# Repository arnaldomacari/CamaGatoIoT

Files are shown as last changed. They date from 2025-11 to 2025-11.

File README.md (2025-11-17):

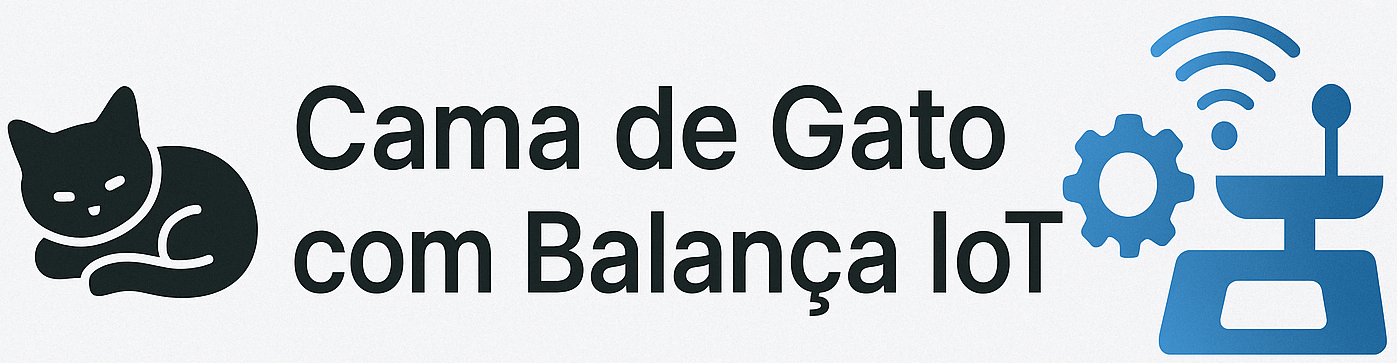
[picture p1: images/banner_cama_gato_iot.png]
Banner do Projeto


<p align="center">
  <span style="font-size:18px; color:blue; font-style:italic;">
    <b>Monitoramento automático de peso e comportamento de felinos com ESP32-C3 Super Mini, HX711 e integração com Google Sheets e Blynk.</b>
  </span>
</p>

---

<p align="center">
  
  
  
  
  
  
</p>

---

## 📘 Resumo

O projeto **Cama de Gato com Balança IoT** propõe o monitoramento automatizado do peso de felinos domésticos, permitindo detectar variações corporais associadas a condições fisiológicas ou patológicas. O sistema usa uma base com **células de carga e módulo HX711**, controlados por um **ESP32-C3** que opera em deep sleep para economizar energia e desperta periodicamente para coletar e enviar dados.

As medições são transmitidas automaticamente para:
- uma **planilha no Google Sheets**, que mantém o histórico e facilita análises;
- o **aplicativo Blynk**, onde o tutor acompanha leituras em tempo real e dispara medições manuais.

---

## 🧠 Objetivos

- Detectar variações sutis de peso corporal em gatos, indicando possíveis doenças metabólicas ou alterações alimentares.
- Desenvolver um sistema de monitoramento contínuo, não invasivo, de baixo custo e com conectividade em nuvem.
- Contribuir para estudos e práticas de bem-estar animal e telemetria veterinária.

---

## 📝 Justificativa

De acordo com dados do Instituto Pet Brasil apresentados por LUCCA (2025) no Correio Braziliense, estima-se que os lares brasileiros já abrigam mais de 30 milhões de gatos. A ABINPET (2025) projeta crescimento de 3,5% para o setor pet no mesmo ano, com faturamento que pode chegar a R$ 78 bilhões. Apesar desse cenário favorável, um estudo com 19 milhões de gatos nos Estados Unidos mostrou que 52% deles tiveram a saúde acompanhada apenas uma vez durante toda a vida, sendo o peso corporal um dos indicadores mais simples e relevantes (CAMPIGOTTO et al., 2019). O trabalho também elaborou uma curva de peso em função da idade, útil como referência em consultas veterinárias. O controle do peso corporal tem relação direta com a longevidade: segundo Pennell et al. (2019), em labradores com mais de dez anos, um desvio de apenas 1 kg aumentou em 19% a probabilidade de morte. Por fim, matéria da University of Guelph (2019) destaca que pequenas variações de peso podem indicar problemas de saúde subjacentes, reforçando a recomendação pelo uso contínuo de balanças. 

Alterações discretas no peso corporal são, muitas vezes, os primeiros sinais de enfermidades em felinos e tendem a passar despercebidas em rotinas domésticas convencionais. Ao unir sensores de baixo custo, computação embarcada eficiente e integração com plataformas de visualização de dados, o projeto possibilita acompanhamento longitudinal, embasando decisões veterinárias mais rápidas e assertivas. A solução também serve como prova de conceito para orientar práticas de bem-estar animal apoiadas por IoT, incentivando a comunidade a adaptar e expandir o sistema conforme necessidades específicas.

---

## ⚙️ Arquitetura do Sistema

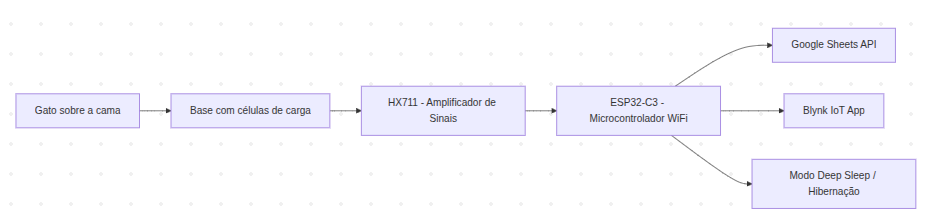
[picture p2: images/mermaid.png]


---

## 🧰 Escolha de Materiais
As células de carga, que transformam o peso do gato em sinal elétrico, precisam ser posicionadas corretamente para que o peso gere uma força de cisalhamento adequada. Para isso, foi desenhado no Onshape um pé e um suporte, mostrados abaixo, que depois foram impressos em 3D usando PLA. O pé e o suporte, junto com a própria célula, também têm a função de elevar a base de MDF onde tudo está fixado, criando um espaço por baixo para a passagem da fiação e para acomodar o circuito eletrônico sem que ambos encostem no chão.
Nos diagramas de Ashby, o MDF aparece na região das madeiras, tem densidade intermediária (600–800 kg/m³) e módulo entre 2–4 GPa. Essa posição o caracteriza como um material rígido, relativamente leve e adequado para estruturas que exigem estabilidade dimensional e baixo custo. No projeto, foi utilizada uma base circular de MDF com raio de 50 cm, espessura de 15 mm e pintada com camadas generosas de tinta epóxi. Essa pintura garante fácil assepsia e alta durabilidade, como mostrado na foto da página anterior.
A caixa do circuito e o porta-fio central também foram impressos em 3D. A manufatura aditiva foi escolhida para o protótipo pela agilidade de produção, considerando a definição da função mecânica da estrutura (rigidez + estabilidade + baixo peso). Na análise de restrições (tamanho, peso do gato e deformação mínima da base), a seleção do polímero PLA levou em conta a facilidade de impressão, baixa deformação, custo, estética e, para garantir maior rigidez, foi utilizado 60% de preenchimento. Inicialmente, usando um paquímetro, foram desenhados no Onshape, com precisão, a célula de carga, a placa do circuito eletrônico (já previamente construída) e a bateria. Com esses elementos modelados, foi possível construir ao redor deles o pé, o suporte, a base do circuito e a caixa.

## 🧩 Componentes Utilizados

| Componente | Função | Observações |
| --- | --- | --- |
| **ESP32-C3** | Microcontrolador principal | Comunicação Wi-Fi e deep sleep |
| **HX711** | Conversor ADC 24 bits | Leitura das células de carga |
| **Células de carga** | Sensor de peso | Montadas em ponte de Wheatstone |
| **Sensor capacitivo** | Interação do usuário | Acorda o sistema do modo de hibernação |
| **Divisor resistivo (R1=R2)**| Monitoramento da bateria | Lido pelo ADC do ESP32-C3 |
| **Fonte/Bateria 5V ou LiPo** | Alimentação | Requer estabilidade para leituras precisas |
| **Google Apps Script** | Integração com planilha | Recebe POST JSON do ESP32-C3 |
| **Blynk App (Free Tier)** | Interface do usuário | Widgets V0, V1, V4, V8 e V9 configurados |
| **Placa perfurada 7cm x 3cm**| Alternativa a placa CI | Suporte aos módulos no 1° teste |

---

## ⚡ Circuitos
### Visão geral da conexão entre ESP32-C3, HX711, células de carga e alimentação.

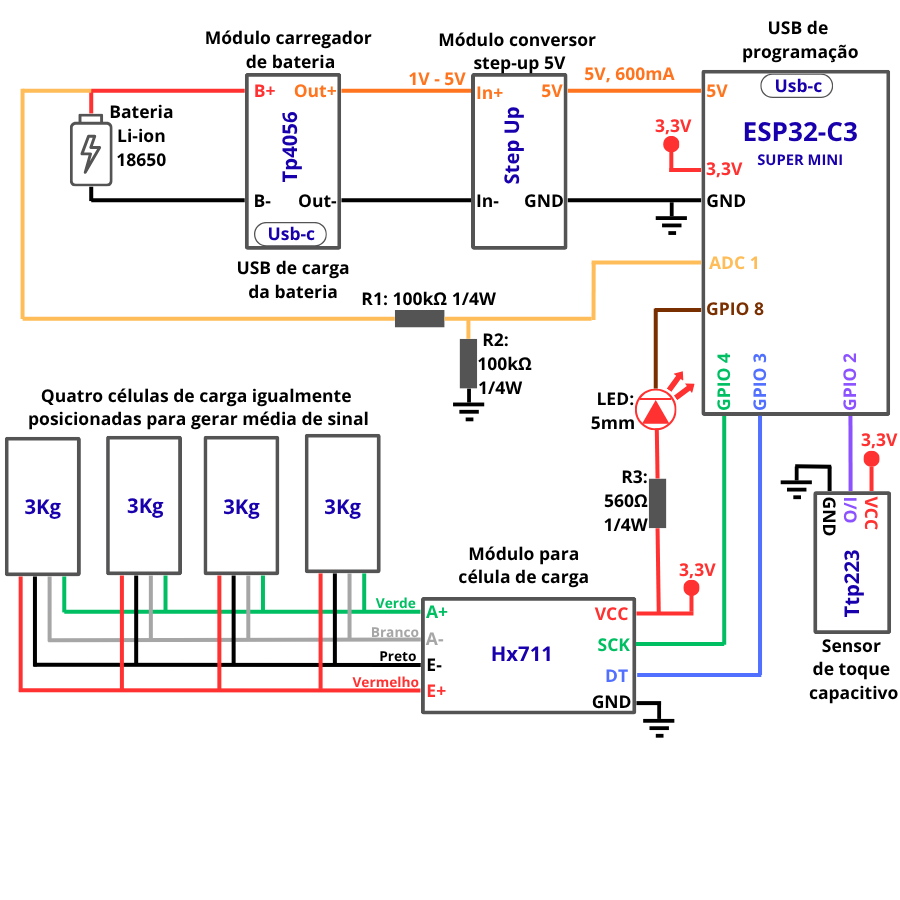
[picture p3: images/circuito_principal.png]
Circuito_principal


---

## 🖼️ Imagens do Protótipo
### Partes mecânicas
#### Pés e bases para células de carga
Usados para posicionar corretamente as células de carga, garantindo que o peso do gato provoque a deformação adequada.

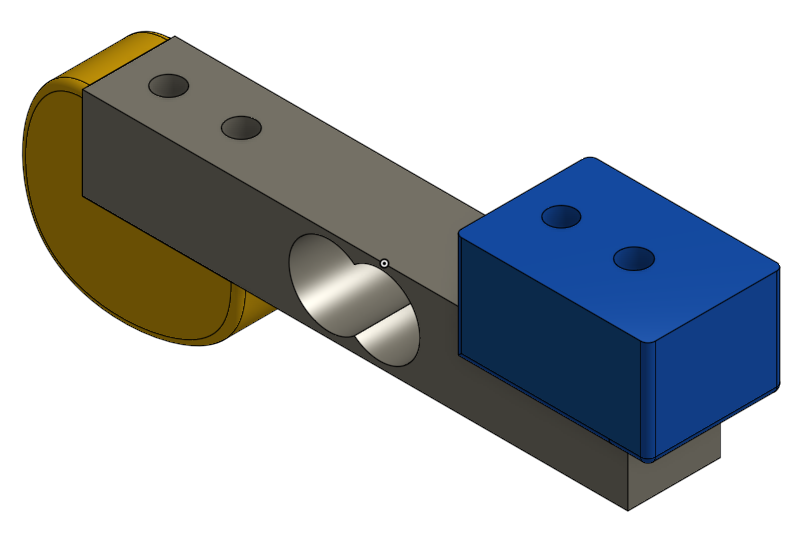
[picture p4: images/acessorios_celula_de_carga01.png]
Acessorios_Celula_de_Carga

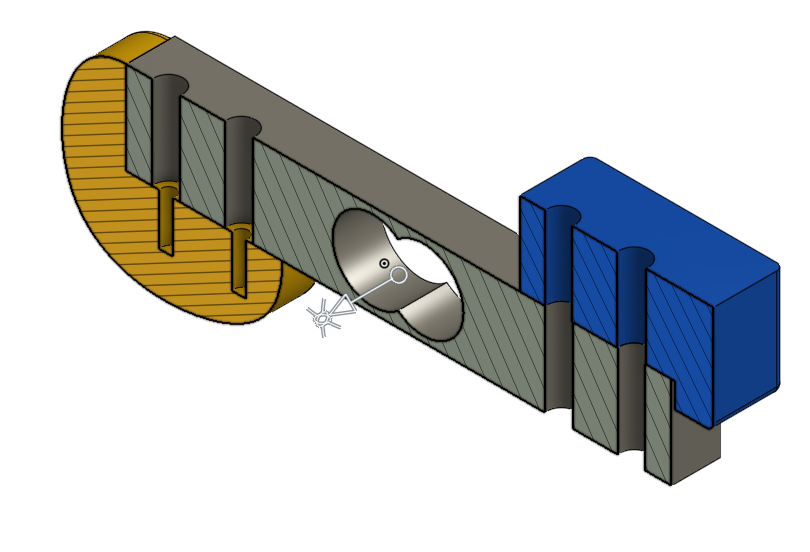
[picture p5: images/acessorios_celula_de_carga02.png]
Acessorios_Celula_de_Carga


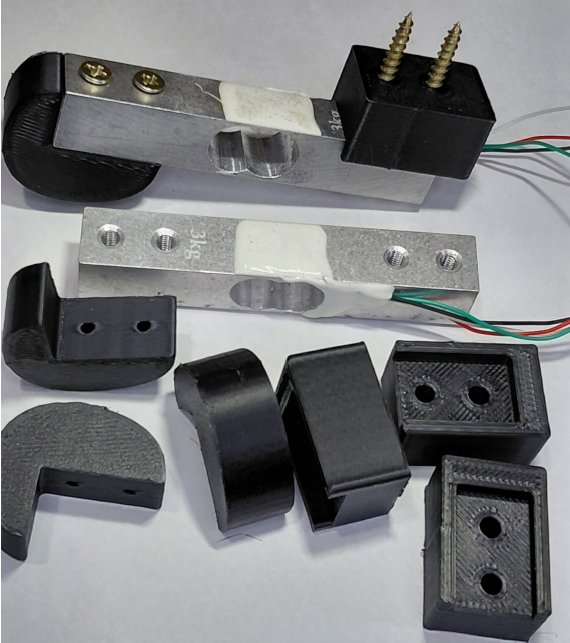
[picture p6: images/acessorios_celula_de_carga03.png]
Acessorios_Celula_de_Carga

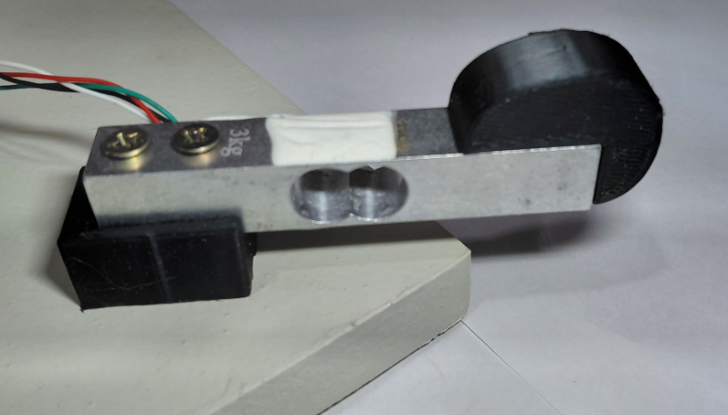
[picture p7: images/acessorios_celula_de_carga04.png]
Acessorios_Celula_de_Carga

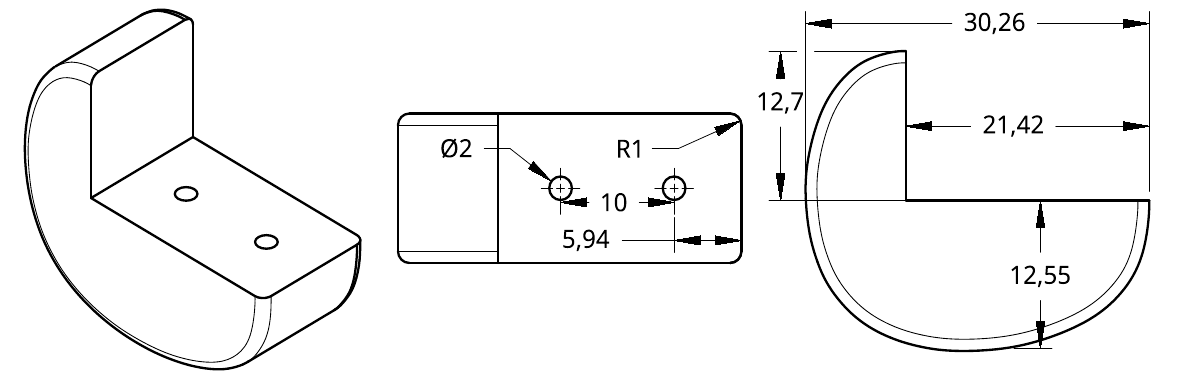
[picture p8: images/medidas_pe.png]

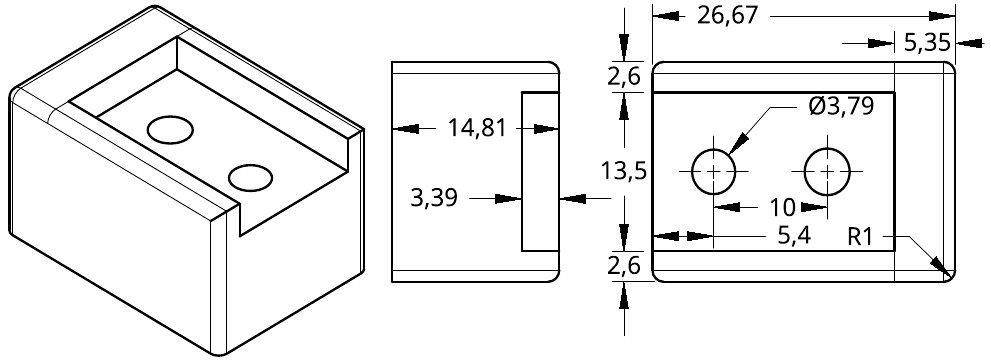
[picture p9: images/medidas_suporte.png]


#### Organizador de fios 
Usado para esticar e esconder as emendas de fios das células de carga com o cabo que segue para a caixa de circuitos.

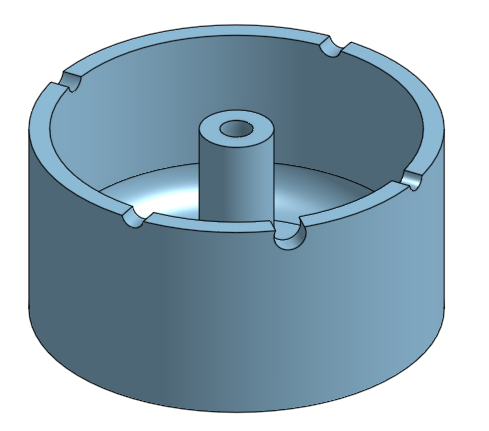
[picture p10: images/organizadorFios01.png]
Organizador1

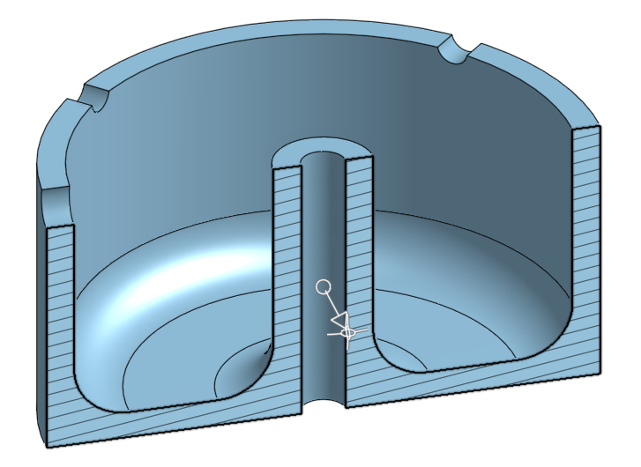
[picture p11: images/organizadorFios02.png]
Organizador2

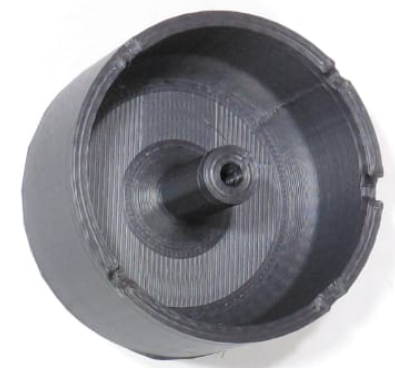
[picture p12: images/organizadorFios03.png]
Organizador3

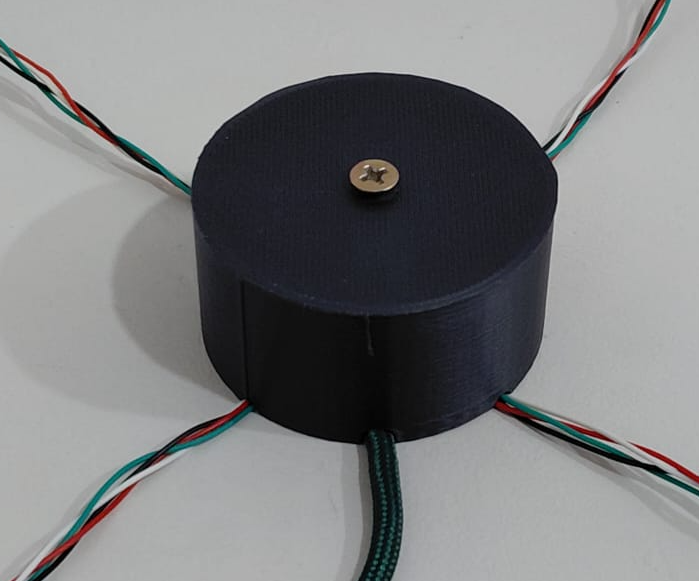
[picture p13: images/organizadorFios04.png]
Organizador4

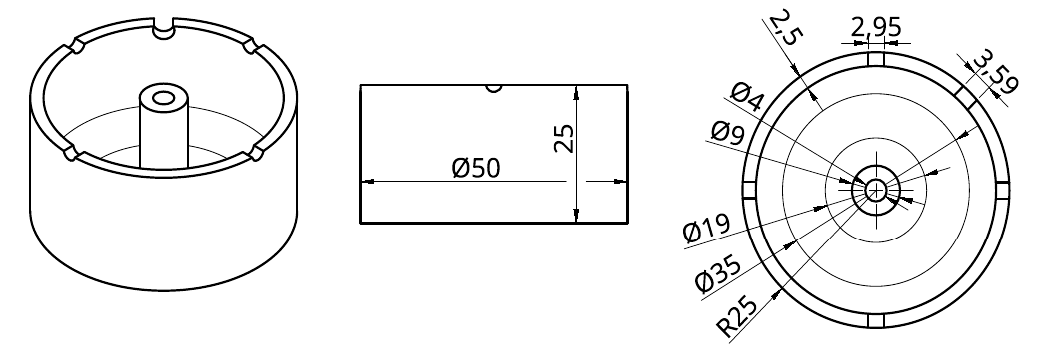
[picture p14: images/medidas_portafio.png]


#### Caixa de circuitos
Caixa que abriga os circuitos, posicionando adequadamente a placa, a bateria, o LED e o botão.
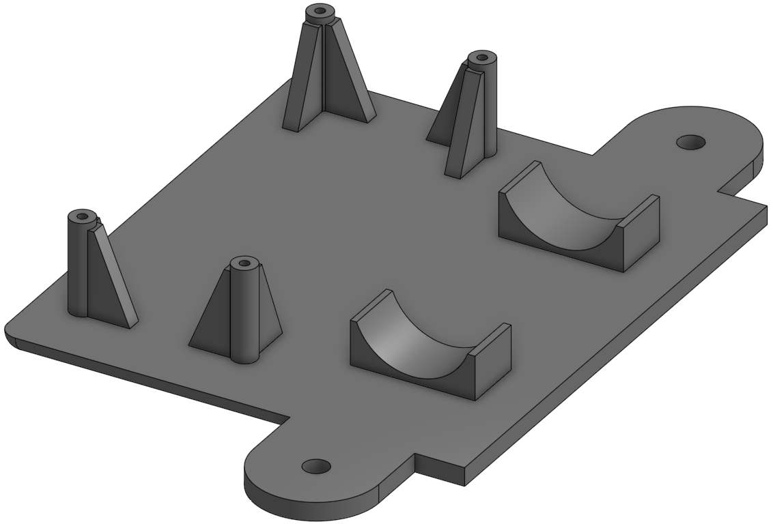
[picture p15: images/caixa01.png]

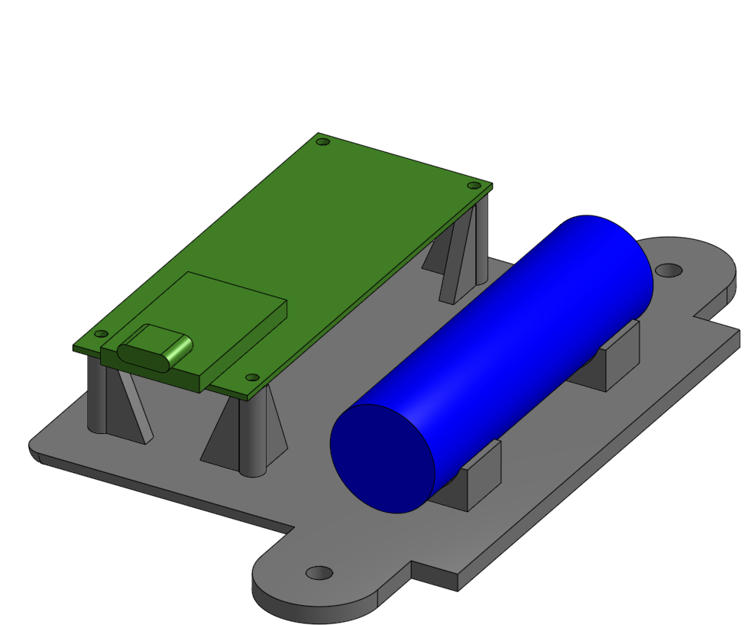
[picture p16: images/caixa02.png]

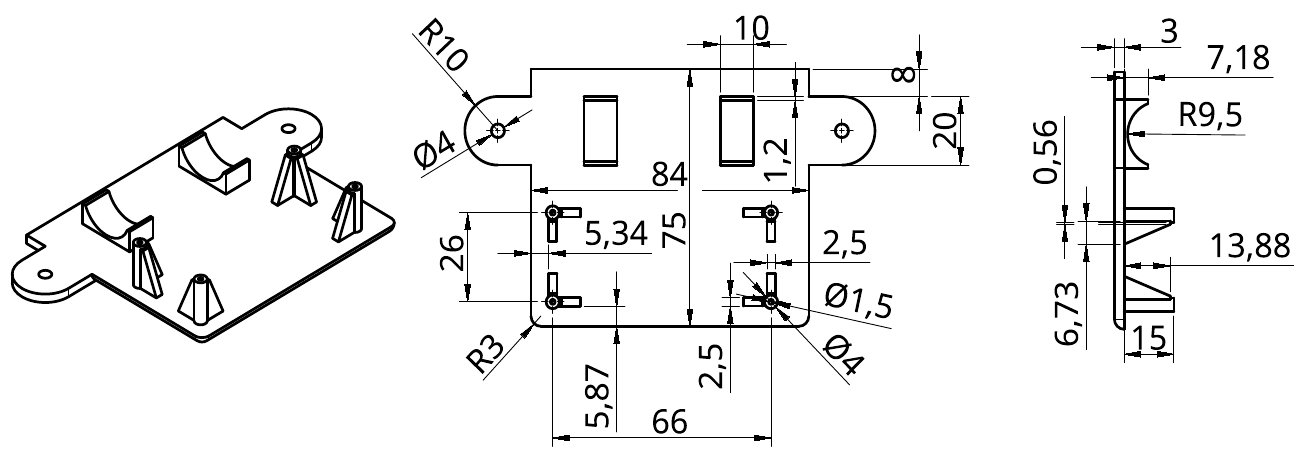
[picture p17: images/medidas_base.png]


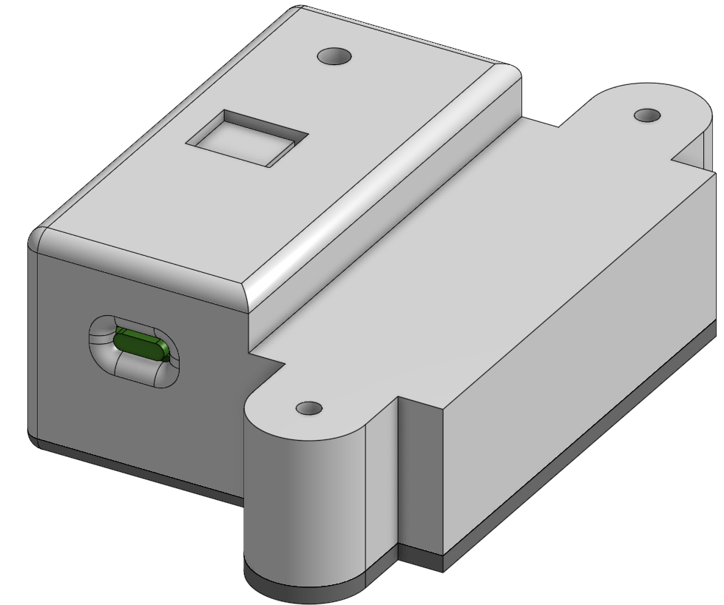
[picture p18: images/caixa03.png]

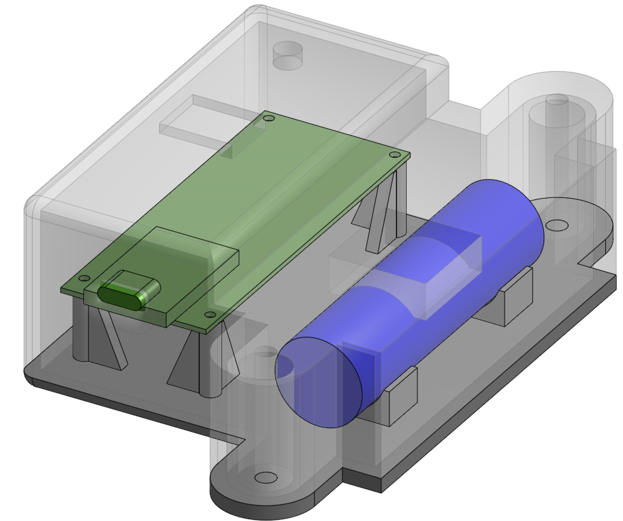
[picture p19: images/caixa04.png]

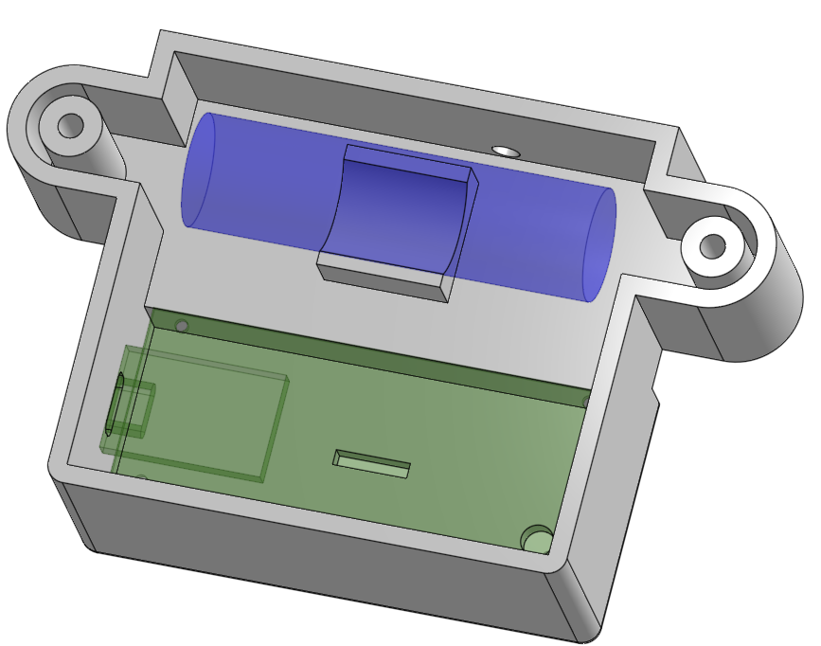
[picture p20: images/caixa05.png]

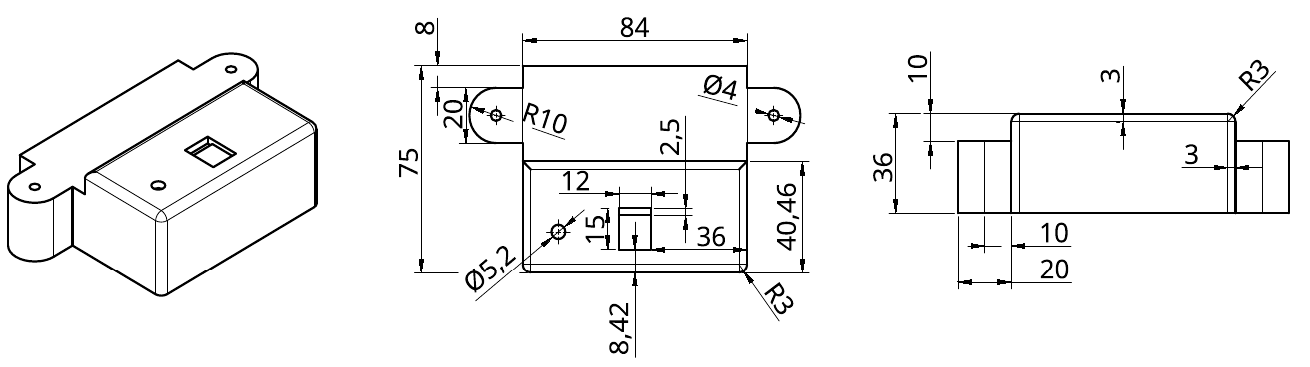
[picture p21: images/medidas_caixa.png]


### Partes eletrônicas
#### Teste em protoboard.
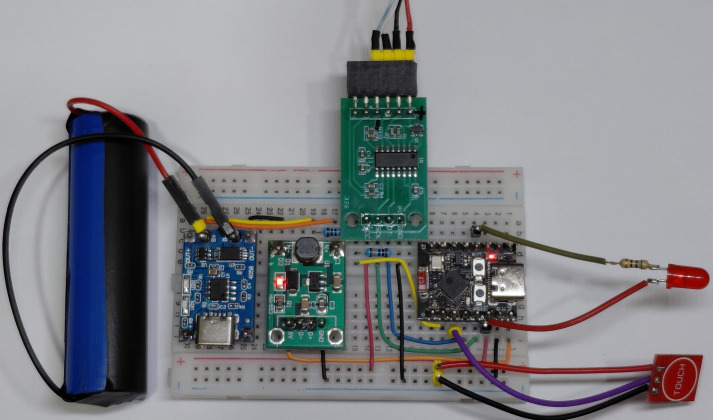
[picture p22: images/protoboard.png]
Protoboard


#### Circuito para teste final.
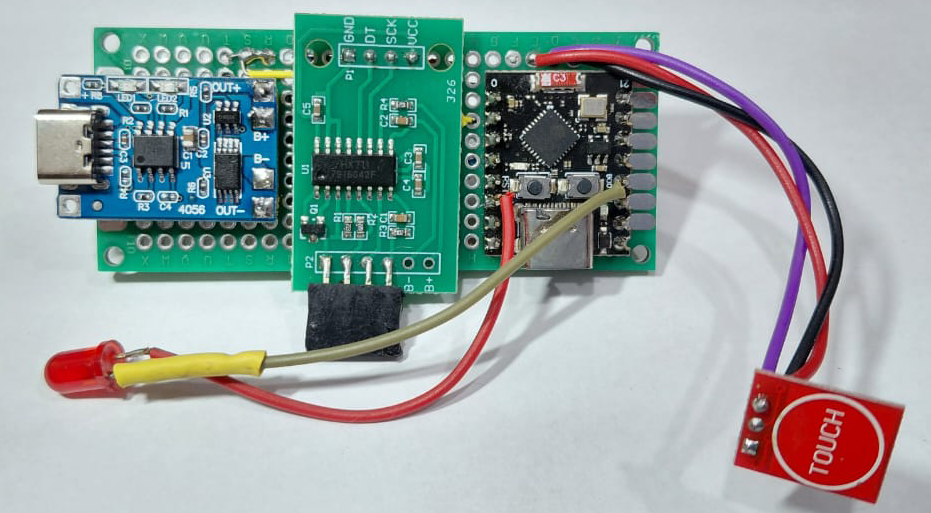
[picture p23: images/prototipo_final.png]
Placa


#### Base pequena para teste de bancada.
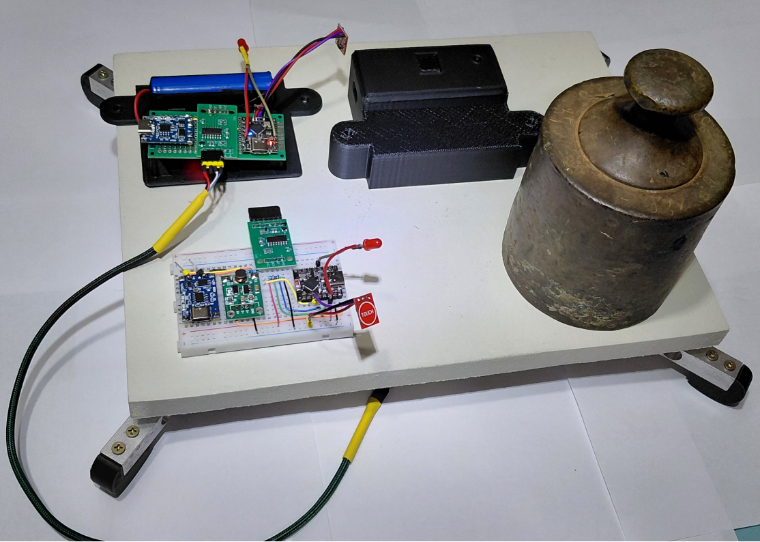
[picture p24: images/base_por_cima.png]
Base1

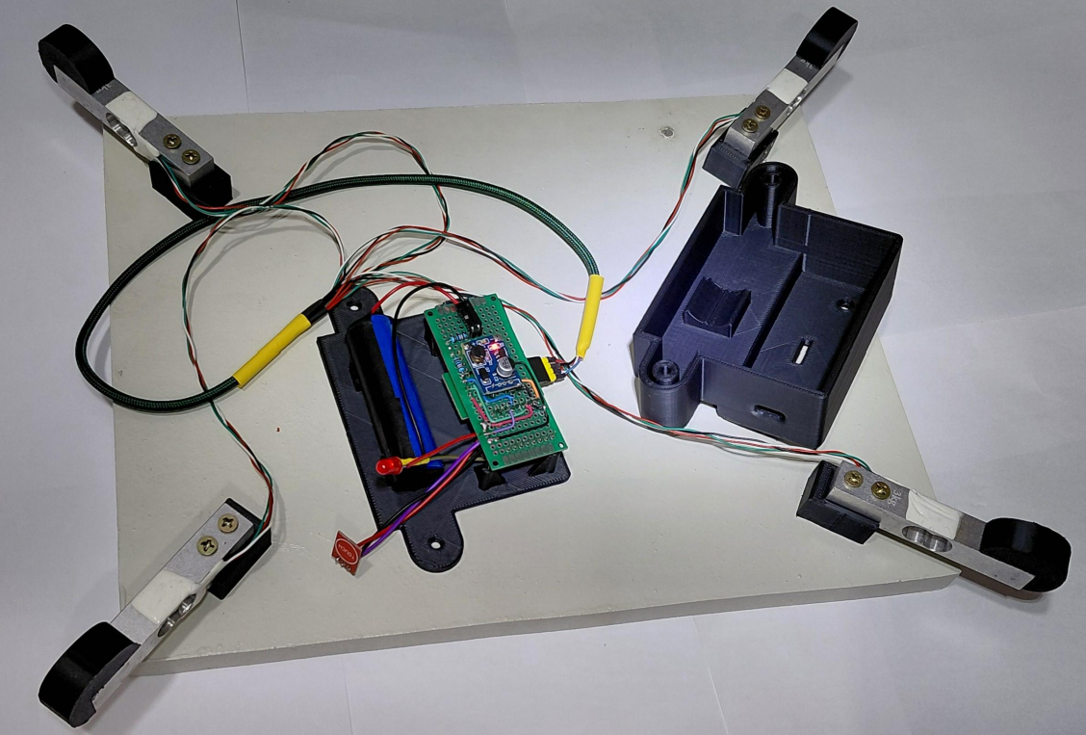
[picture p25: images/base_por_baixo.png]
Base2


#### Finalizando
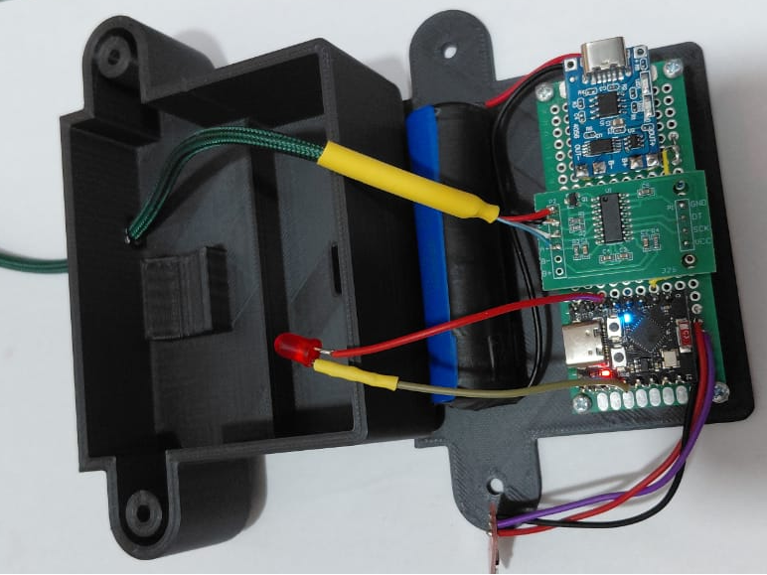
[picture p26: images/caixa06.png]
caixa1

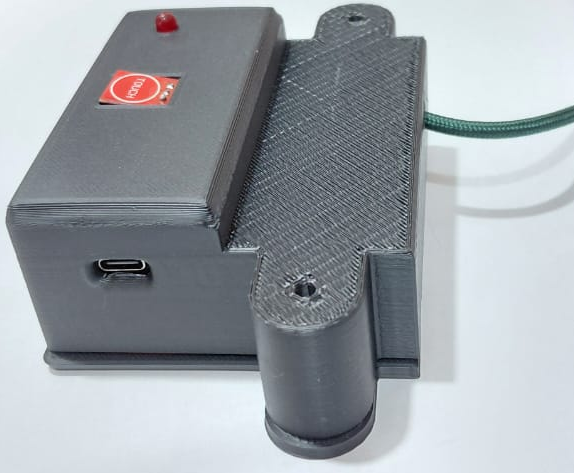
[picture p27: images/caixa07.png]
caixa2

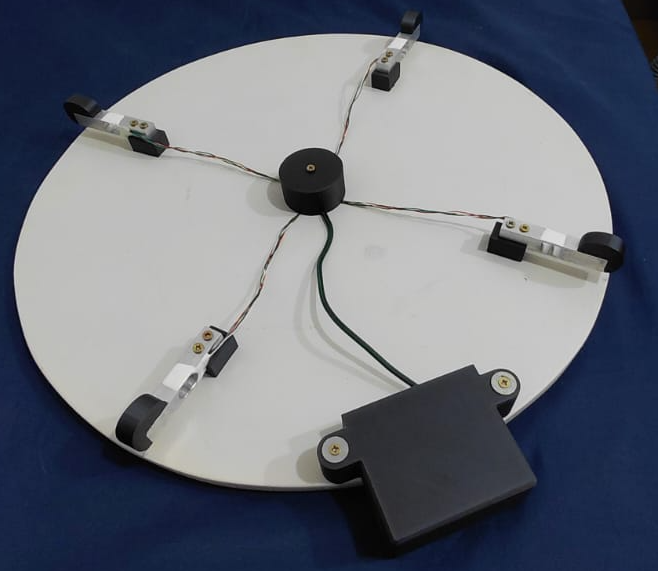
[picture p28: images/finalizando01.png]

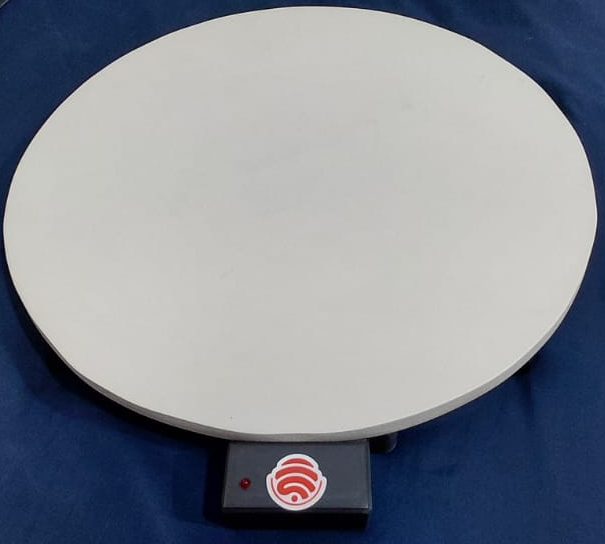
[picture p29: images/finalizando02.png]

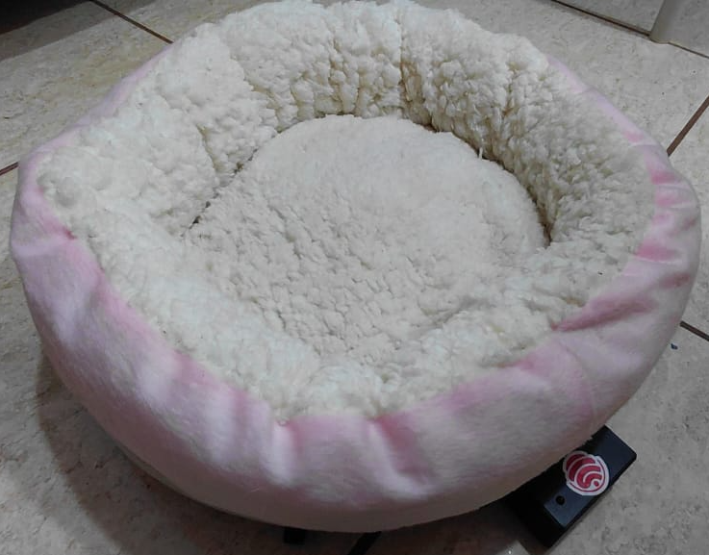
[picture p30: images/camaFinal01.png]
caixa3


---

## 🔄 Funcionamento

- A cada ~10 minutos o ESP32-C3 acorda do deep sleep.
- Verifica se há peso ≥ 300 g acima da tara; caso contrário volta a dormir.
- Se detectar massa relevante, compara com a última leitura enviada:
  - se passaram ≥ 24 h ou houve variação ≥ 100 g, registra o novo valor;
  - envia peso e nível de bateria para o Google Sheets e para o Blynk.
- O usuário pode acordar o sistema com o botão capacitivo para:
  - solicitar uma nova pesagem manual (widget `V0`);
  - tarar a balança (widget `V1`).
- Sem interação manual, o dispositivo volta a dormir após ~5 minutos acordado.

---

## 🛠️ Requisitos de Software

- Arduino IDE ≥ 2.0 ou PlatformIO com suporte a ESP32-C3.
- Bibliotecas:
  - [ESP32 Arduino Core](https://github.com/espressif/arduino-esp32) (inclui `WiFi`, `Preferences`, `esp_sleep`).
  - [HX711](https://github.com/bogde/HX711).
  - [Blynk](https://github.com/blynkkk/blynk-library) (com `BlynkMultiClient`).
- Conta Google com acesso ao Apps Script e Google Sheets.
- Conta Blynk (Free Tier compatível).

### Bibliotecas instaladas na Arduino IDE
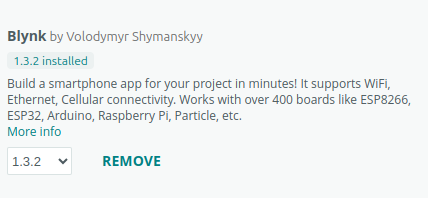
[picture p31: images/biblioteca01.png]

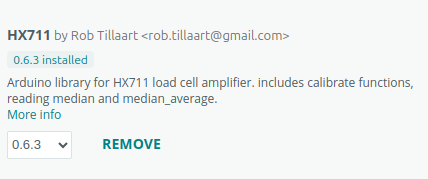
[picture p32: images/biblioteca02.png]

---

## 🚀 Como Começar

1. **Monte o protótipo seguindo as imagens acima**

2. **Clonar o repositório**
   ```bash
   git clone https://github.com/arnaldomacari/CamaGatoIoT.git
   cd CamaGatoIoT
   ```

3. **Criar `senhas.h`** (não versionado) na raiz do projeto:
   ```cpp
   #define yourSSID "NOME_DA_REDE"
   #define yourPASS "SENHA_DA_REDE"
   #define yourScriptURL "https://script.google.com/macros/s/SEU_APP/exec"

   #define YOUR_BLYNK_TEMPLATE_ID "TMPLxxxx"
   #define YOUR_BLYNK_TEMPLATE_NAME "Nome do Template"
   #define YOUR_BLYNK_AUTH_TOKEN "token_do_dispositivo"
   ```

---

4. **Selecionar a placa e compilar**
   - Na IDE, escolha a placa. Para este projeto optou-se pela **NoLogo ESP32-C3 Super Mini**.
   - Ajuste a porta serial e compile.
   - Faça upload e monitore a serial a 115200 bps (ativando `#define debug` para logs detalhados).

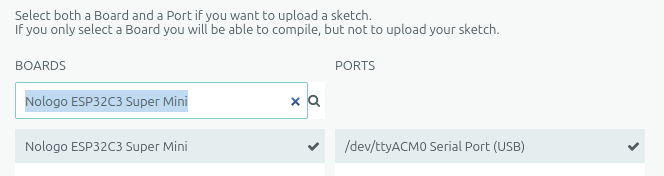
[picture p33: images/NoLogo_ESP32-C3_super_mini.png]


5. **Calibração e Operação**

A biblioteca do **RobTillaart** para o HX711 fornece um exemplo específico para calibrar a balança. 

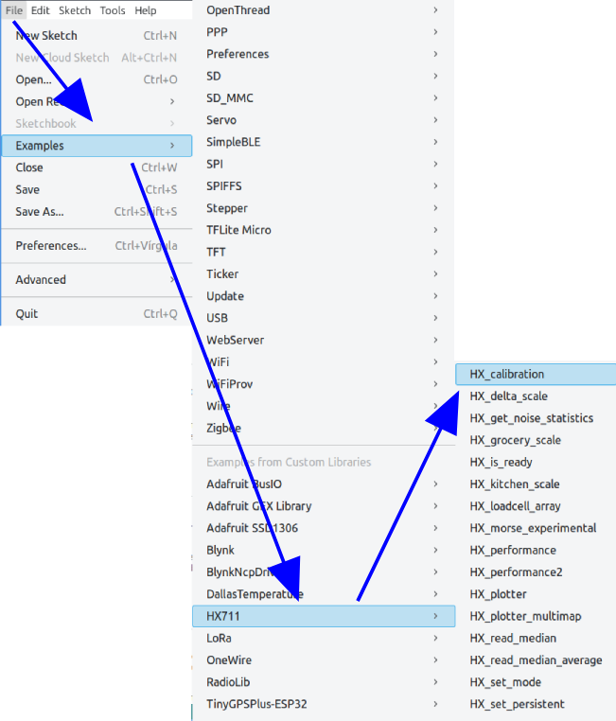
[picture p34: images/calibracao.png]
Calibracao


- Abra o exemplo.
- Ajuste as linhas **13 e 14** como mostrado abaixo:
```cpp
  uint8_t dataPin = 3;  
  uint8_t clockPin = 4;
```
- Grave o sketch no ESP32. 
- Com o auxílio de um **peso conhecido**, siga as instruções exibidas no Monitor Serial da IDE Arduino.  
  - Se o monitor serial não estiver aparecendo, pressione **Ctrl + Shift + M** para abrí-lo.
  - Se estiver usando um ESP com conexão USB direta, como o **ESP32-C3 Super Mini**, inclua um **delay** após iniciar a porta serial:

```cpp
void setup()
{
  Serial.begin(115200);
  delay(1000);  // espera o Monitor Serial se conectar na USB Serial 
```

- Ao final, serão exibidos **valores de calibração** semelhantes a:

```cpp
WEIGHT: 3000
SCALE:  135.926117

use **scale.set_offset(253466)**; and **scale.set_scale(135.926117)**;
in the setup of your project 
```

- Substitua os valores no código **CamaGatoIoT.ino** como mostrado abaixo:

```cpp
// Calibração em tempo de projeto
#define scalaPrefIni 135.926117
#define offsetPrefIni 253466
```

Na primeira vez que usar ou sempre que alterar a base (por exemplo, com uma cama nova), tarar a balança via app Blynk garante leituras consistentes.

---

6. **Configurar o Blynk**
   - Crie um template com widgets:
     - `V0` botão momentâneo (Pesagem manual).
     - `V1` botão momentâneo (Tara).
     - `V4` display numérico (Tensão da bateria).
     - `V5` botão momentâneo (Desligar circuito eletrônico).
     - `V8` display numérico (Peso atual em kg).
     - `V9` gráfico ou histórico (Últimos envios em kg).
   - Copie `Template ID`, `Template Name` e `Auth Token` para `senhas.h`.

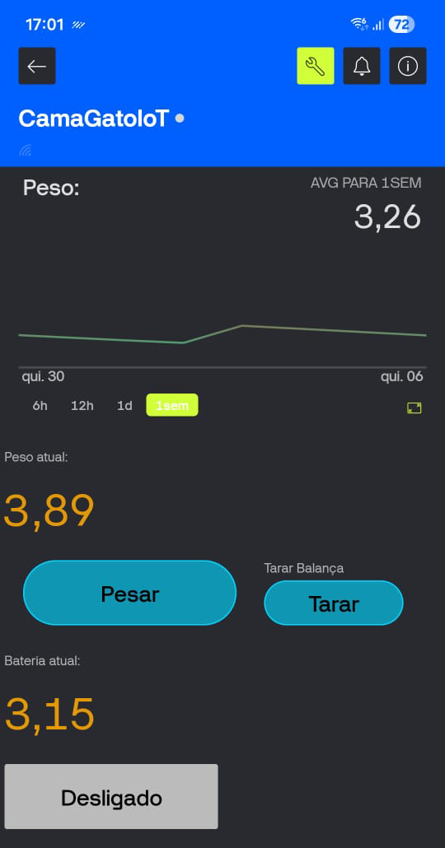
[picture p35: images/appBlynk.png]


7. **Publicar o Google Apps Script**
   - Crie uma planilha e um Apps Script para receber POST com JSON (`peso`, `temperatura`, `bateria`). 

```javascript
function doPost(e) {
  var sheet = SpreadsheetApp.getActiveSpreadsheet().getSheetByName("Página1");
  var data = JSON.parse(e.postData.contents);

  sheet.appendRow([
    new Date(),
    data.peso,
    data.temperatura, // reservado para futuros testes
    data.bateria
  ]);

  // --- Atualiza sempre a célula fixa com o último valor ---
  // --- Utilizado para mostrar o último valor no gráfico de medidor e no geral
  sheet.getRange("G1").setValue(new Date());
  sheet.getRange("H1").setValue(data.peso);
  sheet.getRange("I1").setValue(data.temperatura); // reservado para futuros testes
  sheet.getRange("J1").setValue(data.bateria);

  return ContentService
           .createTextOutput("OK")
           .setMimeType(ContentService.MimeType.TEXT);
}
```

   - Publique como aplicação web acessível a qualquer pessoa com o link.
   - Cole a URL gerada em `yourScriptURL` em  **senhas.h**.

## 🔋 Ajuste da Curva da Tensão da Bateria

O monitoramento da bateria utiliza o ADC do ESP32-C3 lendo um divisor resistivo. Para que a tensão exibida no Blynk e no Google Sheets corresponda ao valor real, foi feito um ajuste de curva:

| Blynk (V) | Multímetro (V) | Equação Ajustada (V) | Erro (V) |
| ---: | ---: | ---: | ---: |
| 4,42 | 4,14 | 4,15 | -0,02 |
| 4,30 | 3,94 | 3,96 | -0,02 |
| 3,94 | 3,52 | 3,53 | -0,01 |
| 3,19 | 2,95 | 2,94 | 0,01 |
| 3,04 | 2,81 | 2,80 | 0,01 |

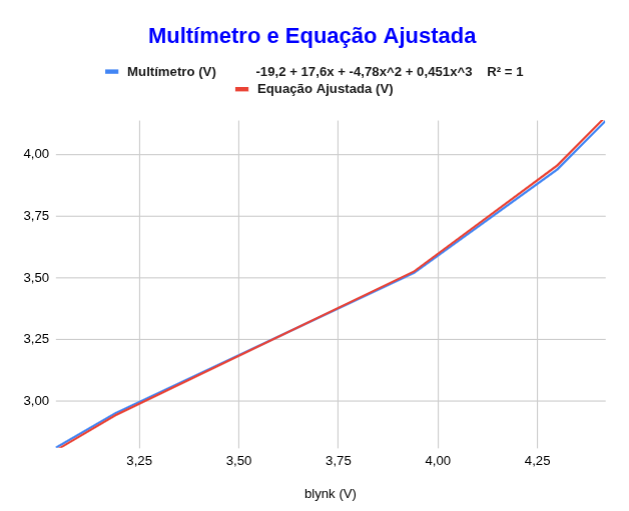
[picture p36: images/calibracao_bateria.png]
Calibracao


```cpp
float valorBateria(void) {
  analogReadResolution(12);  // 12 bits (0-4095)
  int leitura = analogRead(PINO_BATERIA);
  float tensao_adc = (leitura / 4095.0) * 3.3;  // AD de 12bits para 3.3V
  float x = tensao_adc * ((R1 + R2) / R2);      // Compensa o divisor de tensão
  float tensao_bateria = -19.2 + 17.6*x + -4.78*x*x + 0.451*x*x*x;  // Corrige valores lidos usando 
                                                                    // uma curva cúbica e tendo como  
                                                                    // referência as leituras de 
                                                                    // um multímetro
```                                                                    

Esse procedimento garante que alertas de bateria baixa e gráficos históricos representem fielmente a autonomia do sistema.

## 💾 Estrutura do Repositório

- `CamaGatoIoT.ino` – firmware principal com máquina de estados, leituras e integrações.
- `senhas.h` – credenciais locais (conforme descrito acima; mantenha fora do versionamento).
- `images/` – diagramas e fotos do protótipo.
- `arquivos3D/` – modelos 3D para impressão e ajustes mecânicos.
- `LICENSE` – licença MIT.

---

## 📊 Exemplo de Planilha Google

- Campos sugeridos: `timestamp`, `peso_kg`, `bateria_v`; o campo de temperatura fica reservado para uma expansão futura.

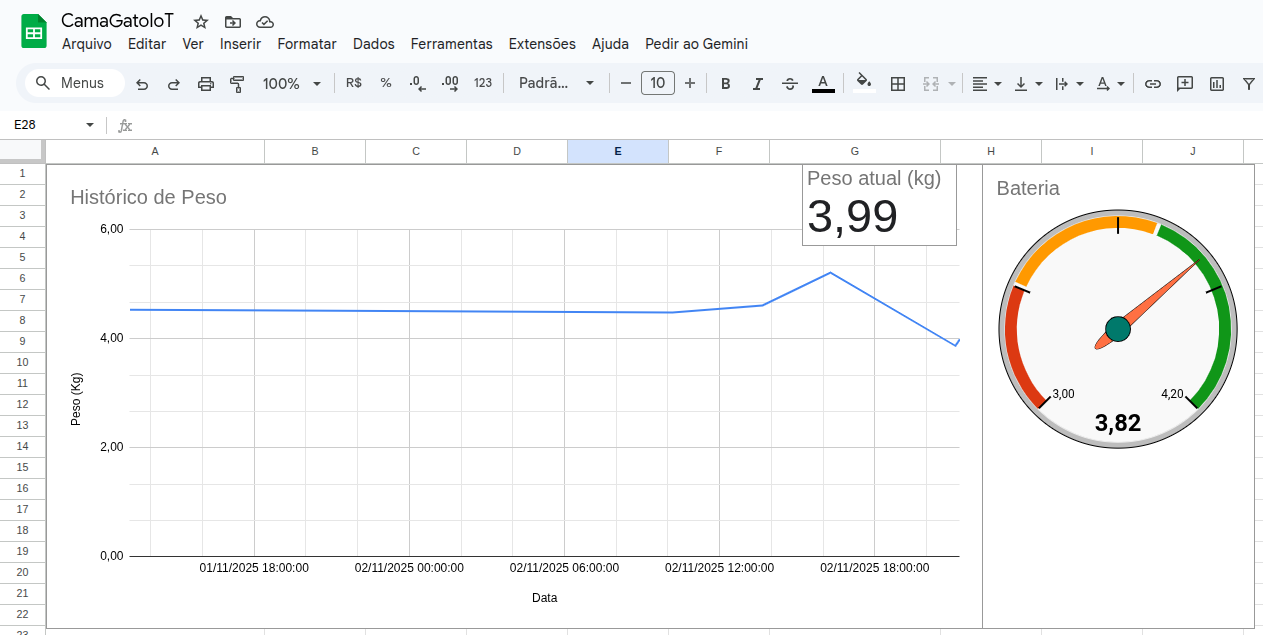
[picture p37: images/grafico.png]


---

## 🧪 Testes e Métricas Atuais

**Ainda em execução**

---

## 📥 Downloads de Arquivos para Impressão 3D

| Base da Caixa | Caixa | Organizador de Fios | Pé da Célula de Carga | Suporte para Célula de Carga |
|:---:|:-----:|:---:|:---:|:---:|
|  |  |  |  |  |

- [Modelos 3D (`arquivos3D/`)](arquivos3D) – peças da estrutura física da cama para impressão e ajustes mecânicos.

---

## 📚 Referências

- ABINPET. **Setor pet projeta crescer apenas 3,5% em 2025, com faturamento de R$ 78 bilhões.** 2025. Disponível em: https://www.gov.br/agricultura/pt-br/assuntos/camaras-setoriais-tematicas/documentos/camaras-setoriais/animais-e-estimacao/2025/43a-ro-15-07-2025/release-projecao1tr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. Acesso em: 26 out. 2025.

- CAMPIGOTTO, Adam J. et al. Investigation of relationships between body weight and age among domestic cats stratified by breed and sex. **Journal Of The American Veterinary Medical Association**, [S.L.], v. 255, n. 2, p. 205-212, 15 jul. 2019. American Veterinary Medical Association (AVMA). http://dx.doi.org/10.2460/javma.255.2.205. Disponível em: https://avmajournals.avma.org/view/journals/javma/255/2/javma.255.2.205.xml. Acesso em: 3 nov. 2025.

- LUCCA, B. **Adoção de gatos aumenta no Brasil e 30 milhões de felinos têm um lar.** 2025. Correio Braziliense. Disponível em: Correio Braziliense. Acesso em: 26 out. 2025.

- PENNELL, Johanna Christina; MORGAN, David Mark; WATSON, Penny; CARMICHAEL, Stuart; ADAMS, Vicki Jean. Body weight at 10 years of age and change in body composition between 8 and 10 years of age were related to survival in a longitudinal study of 39 Labrador retriever dogs. **Acta Veterinaria Scandinavica**, [S.L.], v. 61, n. 1, p. 42-48, 9 set. 2019. Springer Science and Business Media LLC. http://dx.doi.org/10.1186/s13028-019-0477-x. Disponível em: https://actavetscand.biomedcentral.com/articles/10.1186/s13028-019-0477-x. Acesso em: 26 out. 2025.

- **UNIVERSITY OF GUELPH**. U of G researchers first to track how cats’ weight changes over time. Guelph: University of Guelph News, 24 jul. 2019. Disponível em: https://news.uoguelph.ca/2019/07/u-of-g-researchers-first-to-track-how-cats-weight-changes-over-time/. Acesso em: 3 nov. 2025.

---

## 👨‍🔬 Autor

**Arnaldo José Macari**  
Engenheiro de Alimentos e Desenvolvedor de Sistemas Embarcados  
São José do Rio Preto – SP, Brasil

---

## 🪪 Licença

Distribuído sob a licença MIT. Consulte o arquivo [`LICENSE`](LICENSE) para mais informações.

---

## 🤝 Contribuição

Contribuições são bem-vindas! Abra uma issue ou envie um pull request com melhorias no firmware, documentação ou design mecânico.

<p align="center">
  <sub>Desenvolvido com ❤️ e curiosidade científica – integrando IoT, automação e bem-estar animal.</sub>
</p>

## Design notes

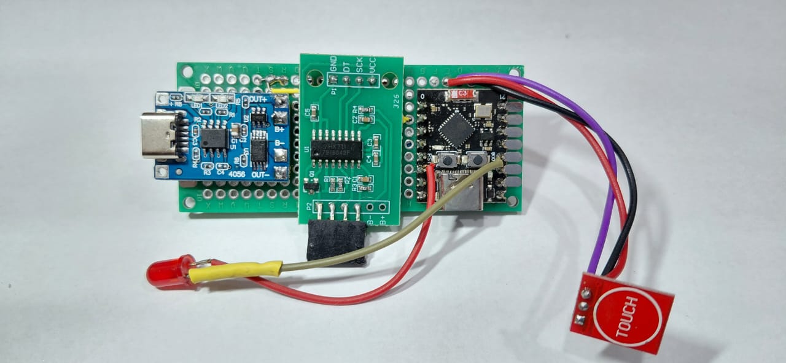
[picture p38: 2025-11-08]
images/prototipo_final.jpeg

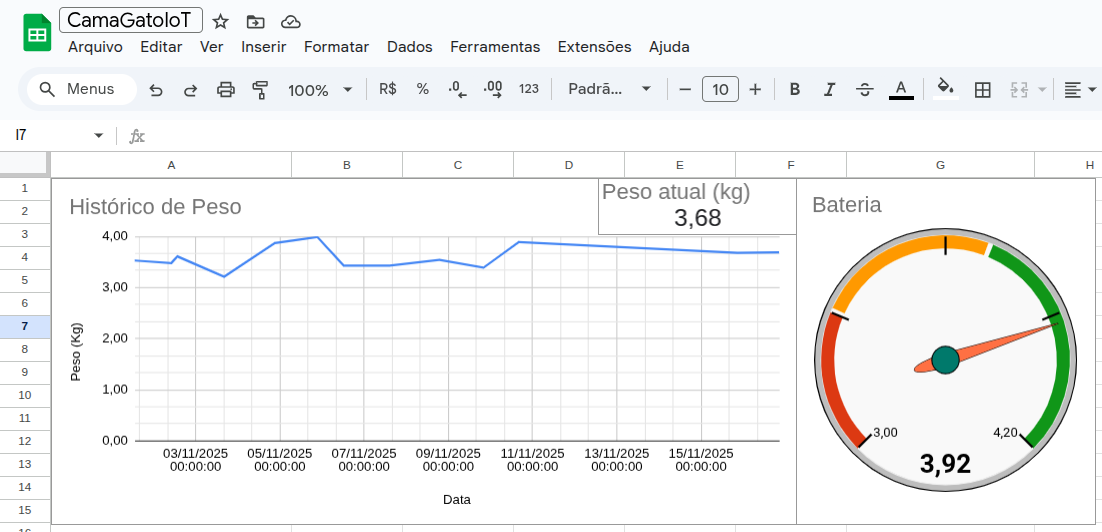
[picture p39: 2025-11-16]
images/grafico1.png

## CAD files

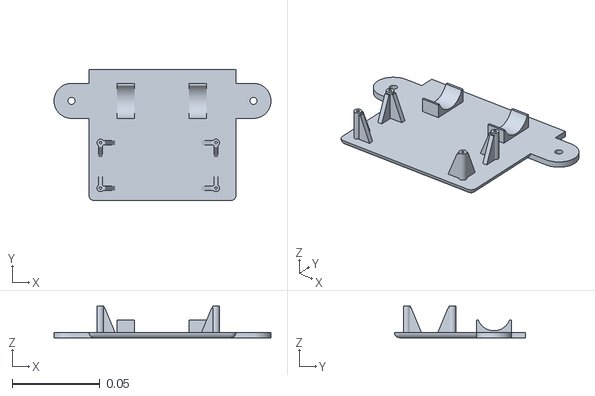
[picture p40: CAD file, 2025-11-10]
arquivos3D/baseCaixa.stl
0.124 x 0.075 x 0.018

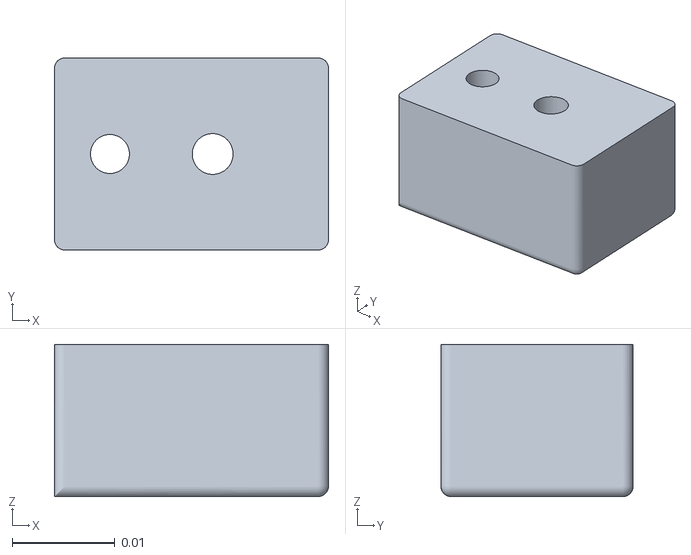
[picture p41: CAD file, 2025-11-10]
arquivos3D/suporteCelulaCarga.stl
0.0267 x 0.0187 x 0.0148

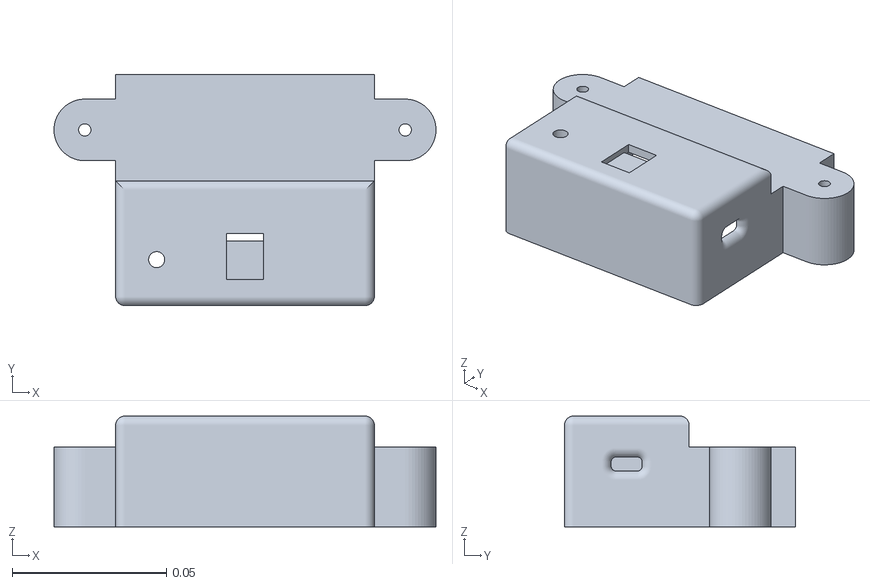
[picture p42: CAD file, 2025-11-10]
arquivos3D/caixa.stl
0.124 x 0.075 x 0.036

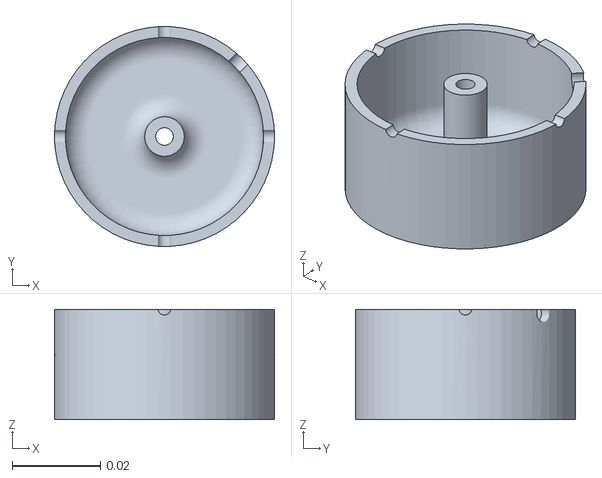
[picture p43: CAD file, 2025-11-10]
arquivos3D/portaFiosCentral.stl
0.05 x 0.05 x 0.025

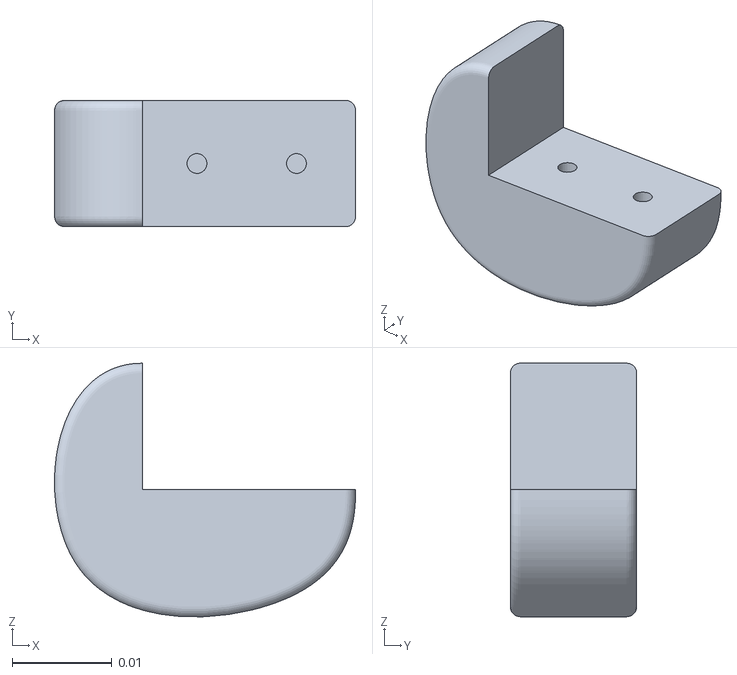
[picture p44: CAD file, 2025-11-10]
arquivos3D/pezinhoCelulaCarga_.stl
0.0302 x 0.0127 x 0.0255

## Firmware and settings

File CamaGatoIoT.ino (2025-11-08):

#include <Arduino.h>
#include <WiFi.h>
#include <esp_sleep.h>
#include "HX711.h"
#include <HTTPClient.h>
#include <Preferences.h>
#include <senhas.h> /*este arquivo não sobe para o github, 
                      trata-se de senhas pessoais. 
                      Siga as instruções no Readme do repositório
                      https://github.com/arnaldomacari/CamaGatoIoT  */


#define debug  //descomente esta linha para debugar o código

// Calibração em tempo de projeto
#define scalaPrefIni 173.870163
#define offsetPrefIni 172004


void connectWiFi(void);
void enviaParaGoogle(float peso, float temperatura, float bateria);

// *******  Automato  *******
int automato = 0;
int automatoDebug = 0;
unsigned long contaPiscadaAnterior = 0;  // will store last time LED was updated
const long intervaloPiscada = 250;       // intervaloPiscada at which to blink (milliseconds)
unsigned long hiberna5min = 0;
const long interval5min = 5 * 60 * 1000;  // 5 minuto * segundo * milesegundos  total= 5 minuto.
int interval24h = 24 * 6;                 // 24horas * 6 * (10)min, pois usa o numero de hibernações, a cada 10min para contar o tempo.
//int interval24h = 6;  // 24horas * 6 * (10)min, pois usa o numero de hibernações, a cada 10min para contar o tempo.
bool status_LED = false;
int contaPiscada = 0;

// ****** Hibernação  *****
const gpio_num_t TOUCH_WAKE_PIN = GPIO_NUM_2;  // ligar ao módulo touch
const uint64_t SLEEP_TIME_US = 10ULL * 60 * 1000000ULL;  // minuto * segundo * microssengundos  total= 10 minutos
//const uint64_t SLEEP_TIME_US = 1ULL * 10 * 1000000ULL;  //  total= 10 segundos para testes
esp_sleep_wakeup_cause_t wakeup_cause;
void goToSleep(void);

// *******  HX711  *******
#define HX711_DT 3   // terminal de dados
#define HX711_SCK 4  // terminal de clock
HX711 scale;
#define pesoMinimo 300                   // g
#define pesoAlteracaoMinima 100          // 100g
RTC_DATA_ATTR float pesoAnterior = 0.0;  // RTC_DATA_ATTR -> não se perde na hibernação
RTC_DATA_ATTR uint32_t contadorSleep = 0;

Preferences prefs;  //  para gravar calibração.
float massaAtual;
float massaModulo;
float scalaPref;
float offsetPref;
float valorMassa(void);


// *******  Bateria  *******
#define PINO_BATERIA 1      // pino ADC usado para o divisor
const float R1 = 100000.0;  // ohms
const float R2 = 100000.0;  // ohms
float bateriaAtual;
float valorBateria(void);


// *******  BLYNK  *******
#define BLYNK_PRINT Serial
#include <BlynkMultiClient.h>
static WiFiClient blynkWiFiClient;
unsigned long startBlynkEnvio;
BLYNK_CONNECTED();
BLYNK_WRITE(V0);
BLYNK_WRITE(V1);


#ifdef debug
#define MySPrint(x) Serial.print(x)
#define MySPrintln(x) Serial.println(x)
#else
#define MySPrint(x)
#define MySPrintln(x)
#endif

void setup() {
  Serial.begin(115200);
  delay(500);
  pinMode(TOUCH_WAKE_PIN, INPUT_PULLDOWN);
  pinMode(LED_BUILTIN, OUTPUT);
  digitalWrite(LED_BUILTIN, LOW);

  do {
    delay(100);
    scale.begin(HX711_DT, HX711_SCK);    //
    MySPrintln("inicializando setup  HX711");
    delay(500);
  } while (!scale.is_ready());
  MySPrintln("HX711 Iniciado com sucesso");
  wakeup_cause = esp_sleep_get_wakeup_cause();

  //Que atitude tomar de acordo de como acordou
  switch (wakeup_cause) {
    case ESP_SLEEP_WAKEUP_TIMER:  // Acordou por estouro de timer
      MySPrintln("Acordou por estouro de timer");
      massaAtual = valorMassa();
      if (massaAtual < pesoMinimo) {  // Se balança vazia.
        MySPrintln("Balanca vazia");
        delay(100);
        goToSleep();  // volta a hibernar
        break;
      };

      massaModulo = massaAtual - pesoAnterior;          // calcula a variação de massa.
      if (massaModulo < 0) massaModulo = -massaModulo;  // calcula o módulo variação de massa.
      if (massaModulo <= pesoAlteracaoMinima) {         // sem alteração significativa
        MySPrint("Peso anterior:");
        MySPrintln(pesoAnterior);
        MySPrintln("Sem alteração de massa significativa, não enviar");
        if (contadorSleep > interval24h) {
          MySPrintln("Estouro de 24 horas");
          pesoAnterior = 0;   //permite reentrada apos 24h
          contadorSleep = 0;  // reinicia contagem de 24h +/-
        }
        delay(100);
        goToSleep();
        break;
      };

      bateriaAtual = valorBateria();  // obtem tensão da bateria
      MySPrintln("Conectando Wifi");
      connectWiFi();  // conecta wifi
      MySPrintln("Enviando para a GOOGLE");
      enviaParaGoogle(massaAtual / 1000, 0, bateriaAtual);  // envia para o google
      MySPrintln("Conectando BLYNK");
      Blynk.addClient("WiFi", blynkWiFiClient, 80);
      Blynk.config(BLYNK_AUTH_TOKEN);
      while (!Blynk.connect()) delay(250);
      MySPrintln("Enviando BLYNK");
      Blynk.virtualWrite(V8, massaAtual / 1000);
      Blynk.virtualWrite(V9, massaAtual / 1000);
      Blynk.virtualWrite(V4, bateriaAtual);
      startBlynkEnvio = millis();                  // Dá tempo para a pilha TCP enviar tudo
      while (millis() - startBlynkEnvio < 1000) {  // aguarda ~1 segundo
        Blynk.run();
        delay(10);
      }
      MySPrintln("Hiberna");
      pesoAnterior = massaAtual;  //evita reentrada se massa for semelhante
      delay(100);
      goToSleep();
      break;

    case ESP_SLEEP_WAKEUP_GPIO:
      MySPrintln("Acordou por gpio");
      hiberna5min = millis();
      if (WiFi.status() != WL_CONNECTED) connectWiFi();
      automato = 1;
      break;

    case ESP_SLEEP_WAKEUP_UNDEFINED:
      MySPrintln("Acordou por causa indefinida");
      delay(100);
      goToSleep();
      break;

    default:
      Serial.printf("Wakeup reason: %d\n", wakeup_cause);
      delay(100);
      goToSleep();
      break;
  }
}





void loop() {
  unsigned long currentMillis = millis();
  // timer para piscar led
  if (currentMillis - contaPiscadaAnterior >= intervaloPiscada && contaPiscada > 0) {
    contaPiscadaAnterior = currentMillis;
    if (status_LED) {
      status_LED = false;
      digitalWrite(LED_BUILTIN, status_LED);
      contaPiscada--;
    } else {
      status_LED = true;
      digitalWrite(LED_BUILTIN, status_LED);
    }
  }

  //Timer para hiberna depois de 5 minutos sem interação com usuário
  if ((wakeup_cause == ESP_SLEEP_WAKEUP_GPIO) && (currentMillis - hiberna5min >= interval5min)) {
    MySPrintln("Hiberna 5 min");
    delay(100);
    goToSleep();
  }


  switch (automato) {
    case 1:
      if (WiFi.status() == WL_CONNECTED) {
        Blynk.addClient("WiFi", blynkWiFiClient, 80);
        Blynk.config(BLYNK_AUTH_TOKEN);
        automato = 2;
      }
      break;

    case 2:
      //terminar aqui
      //apenas aguarda conecção
      //sai desta parte do automato atravez da função BLYNK_CONNECTED
      if (WiFi.status() != WL_CONNECTED) connectWiFi();

      Blynk.run();
      break;

    case 3:
      // futura expansão do código
      Blynk.run();
      break;
  }

  if (automato != automatoDebug) {  // debug para programador acompanhar o automato
    automatoDebug = automato;
    MySPrint("automato = ");
    MySPrintln(automato);
  }
}


void enviaParaGoogle(float peso, float temperatura, float bateria) {
  if (WiFi.status() == WL_CONNECTED) {
    HTTPClient http;
    http.begin(scriptURL);
    http.addHeader("Content-Type", "application/json");
    String jsonData = "{\"peso\": " + String(peso) + ", \"temperatura\": " + String(0) + ", \"bateria\": " + String(bateria) + "}";
    int httpResponseCode = http.POST(jsonData);
    MySPrint("Código HTTP: ");
    MySPrintln(httpResponseCode);
    http.end();
  }
}


float valorMassa(void) {
  /*do {
    scale.power_down();
    delay(100);
    scale.reset();
    delay(100);
    //scale.power_up();
    delay(100);
    //digitalWrite(HX711_SCK, LOW);  /
    scale.begin(HX711_DT, HX711_SCK);
    //
    MySPrintln("inicializando  HX711");
    delay(200);
  } while (!scale.is_ready()); */

  MySPrintln("Calibrando...");
  prefs.begin("config", false);

  do {
    scalaPref = prefs.getFloat("scalaPref_", -1);  // verifica se ja tem valor gravado na memória
    offsetPref = prefs.getFloat("offsetPref_", -1);
    MySPrint("scalaPref: ");
    MySPrintln(scalaPref);
    MySPrint("offsetPref: ");
    MySPrintln(offsetPref);
    if (scalaPref < 0) {
      prefs.putFloat("scalaPref_", scalaPrefIni );  //Se não tem, grava valor calibrado em tempo de desenvolvimento
      MySPrintln("Ajustando escala pela primeira vez");
    }
    if (offsetPref < 0) {
      prefs.putFloat("offsetPref_", offsetPrefIni );  //Se não tem, grava valor calibrado em tempo de desenvolvimento
      MySPrintln("Ajustando offset pela primeira vez");
    }
  } while (scalaPref < 0 || offsetPref < 0);

  scale.set_scale(scalaPref);
  scale.set_offset(offsetPref);  //calibrando
  MySPrintln("Pesando...");
  //scale.power_up();
  delay(100);
  float leitura = scale.get_units(10);  // média de 10 leituras
  
  MySPrint("Peso: ");                                                                      
  MySPrint(leitura);
  MySPrintln("g");
  return leitura;
}


float valorBateria(void) {
  analogReadResolution(12);  // 12 bits (0-4095)
  int leitura = analogRead(PINO_BATERIA);
  float tensao_adc = (leitura / 4095.0) * 3.3;  // AD de 12bits para 3.3V
  float x = tensao_adc * ((R1 + R2) / R2);      // Compensa o divisor de tensão
  float tensao_bateria = -19.2 + 17.6*x + -4.78*x*x + 0.451*x*x*x;  // Corrige valores lidos usando 
                                                                    // uma curva cúbica e tendo como  
                                                                    // referência as leituras de 
                                                                    // um multímetro
  MySPrint("ADC: ");
  MySPrint(leitura);
  MySPrint("  |  Tensão da bateria: ");
  MySPrint(tensao_bateria);
  MySPrintln(" V");
  return tensao_bateria;
}


void connectWiFi(void) {
  MySPrint("Connecting to ");
  MySPrintln(ssid);
  WiFi.begin(ssid, pass);
  while (WiFi.status() != WL_CONNECTED) {
    delay(500);
    MySPrint(".");
  }
}

void goToSleep(void) {
  Blynk.disconnect();
  WiFi.disconnect(true);
  WiFi.mode(WIFI_OFF);
  esp_deep_sleep_enable_gpio_wakeup((1ULL << TOUCH_WAKE_PIN), ESP_GPIO_WAKEUP_GPIO_HIGH);  //
  esp_sleep_enable_timer_wakeup(SLEEP_TIME_US);
  contadorSleep = contadorSleep + 1;  // opcional: timer backup
  MySPrint("Entrando em deep sleep n");
  MySPrintln(contadorSleep);
  MySPrintln("\n");
  scale.power_down();
  digitalWrite(LED_BUILTIN, HIGH);
  delay(10);
  esp_deep_sleep_start();
}


BLYNK_CONNECTED() {
  MySPrintln("blink conectado");

  digitalWrite(LED_BUILTIN, HIGH);  // turn the LED on (HIGH is the voltage level)
  contaPiscada = 5;
  hiberna5min = millis();
  Blynk.virtualWrite(V5, 1);
  automato = 3;
}


BLYNK_WRITE(V0) {  //PESA
  int value = param.asInt();
  MySPrint("V0 acionado: ");
  MySPrintln(value);
  MySPrintln("Enviando dados para BLYNK");  //RTC_DATA_ATTR float taraVolatil = 0;
  bateriaAtual = valorBateria();
  massaAtual = valorMassa();
  if (massaAtual > pesoMinimo) {
    MySPrintln("Enviando dados para BLYNK");
    Blynk.virtualWrite(V8, massaAtual / 1000);
  } else {
    MySPrintln("Não atingio valor minimo para envio");
  }
  Blynk.virtualWrite(V9, massaAtual / 1000);
  Blynk.virtualWrite(V4, bateriaAtual);
  Blynk.virtualWrite(V0, 0);

  if (massaAtual > pesoMinimo) {
    MySPrintln("Enviando dados para google");
    enviaParaGoogle(massaAtual / 1000, 0, bateriaAtual);
  } else {
    MySPrintln("Não atingio valor minimo para envio");
  }
  hiberna5min = millis();
  contaPiscada = 2;
}

BLYNK_WRITE(V1) {  // TARA A BALANÇA
  int value = param.asInt();
  MySPrint("V1 acionado: ");
  MySPrintln(value);
  scale.tare();
  prefs.begin("config", false);
  float taraTemp = scale.get_offset();
  prefs.putFloat("offsetPref_", taraTemp);  // grava a nova tara no
  MySPrintln("Ajustando offset por comando do Blynk");
  bateriaAtual = valorBateria();
  Blynk.virtualWrite(V9, 0);
  Blynk.virtualWrite(V4, bateriaAtual);
  Blynk.virtualWrite(V1, 0);
  hiberna5min = millis();
  contaPiscada = 2;
}

BLYNK_WRITE(V5) {
  int value = param.asInt();
  MySPrintln(value);
  startBlynkEnvio = millis();
  if (value == 0) {
    Blynk.virtualWrite(V5, 0);
    while (millis() - startBlynkEnvio < 1000) {  // aguarda ~1 segundo
      Blynk.run();
      delay(10);
    }
    goToSleep();
  }
}

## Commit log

2025-11-02 Adicionado botão de desligar no app
2025-11-10 Readme Atualizado 05
    [baseCaixa.stl, caixa.stl, pezinhoCelulaCarga_.stl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]
